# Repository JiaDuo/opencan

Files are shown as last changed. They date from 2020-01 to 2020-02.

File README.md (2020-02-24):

# opencan
linux系统下开源的can测试工具
基于linux驱动中slcan协议实现socketcan的通信  

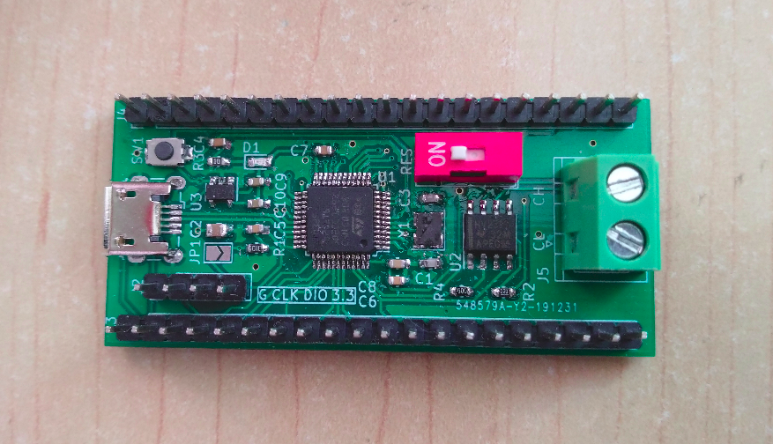
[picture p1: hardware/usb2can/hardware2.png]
Image text


## 硬件介绍  
硬件使用MicroUSB和PC主机通信，支持一路CAN 2.0B，最大波特率1Mbps
## 更新固件
使用stlink/jlink连接到J2引脚，CLK DIO GND  

linux系统下安装stlink-tools  
apt install stlink-tools  

下载固件到MCU中  
st-flash --reset write ./build/usb2can.bin 0x08000000  

## 使用
基于slcan/socketcan的软件都可以应用到当前设备，python-can、can-utils等     
* 安装can-utils  
apt install can-utils
* 建立socketcan设备  
slcand -o -s8 /dev/ttyACM0 can0   
ip link set up can0
* 收发报文
可以使用ifconfig查看can网络状态，使用can-utils中提供的软件来进行报文收发  
eg：  
candump can0  
cansniffer -c can0  
cansend can0 123#R3  

## 一些参考文档
[slcan]https://elinux.org/Bringing_CAN_interface_up  
[slcan-api]https://github.com/linux-can/can-misc/blob/master/docs/SLCAN-API.pdf

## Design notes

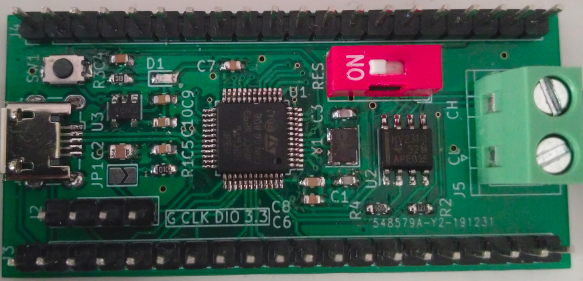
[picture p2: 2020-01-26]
hardware/usb2can/hardware.png

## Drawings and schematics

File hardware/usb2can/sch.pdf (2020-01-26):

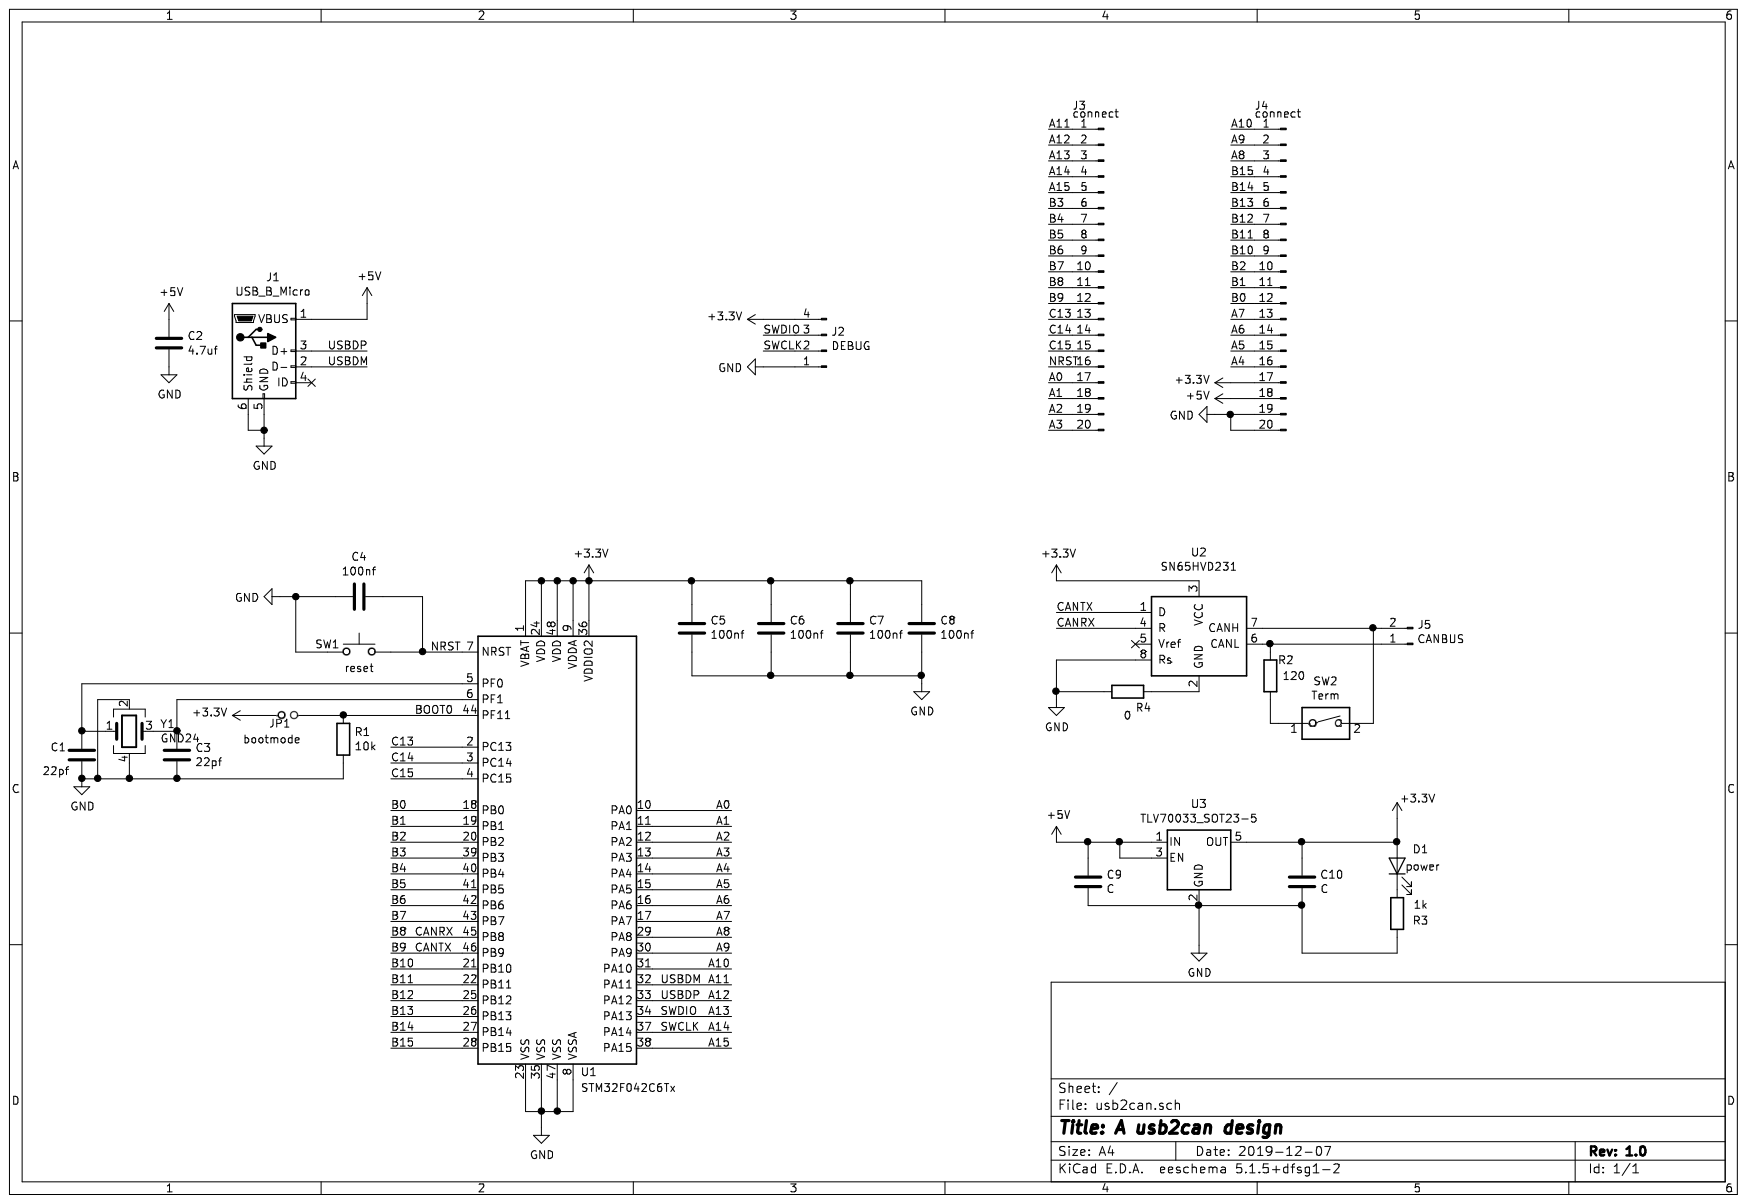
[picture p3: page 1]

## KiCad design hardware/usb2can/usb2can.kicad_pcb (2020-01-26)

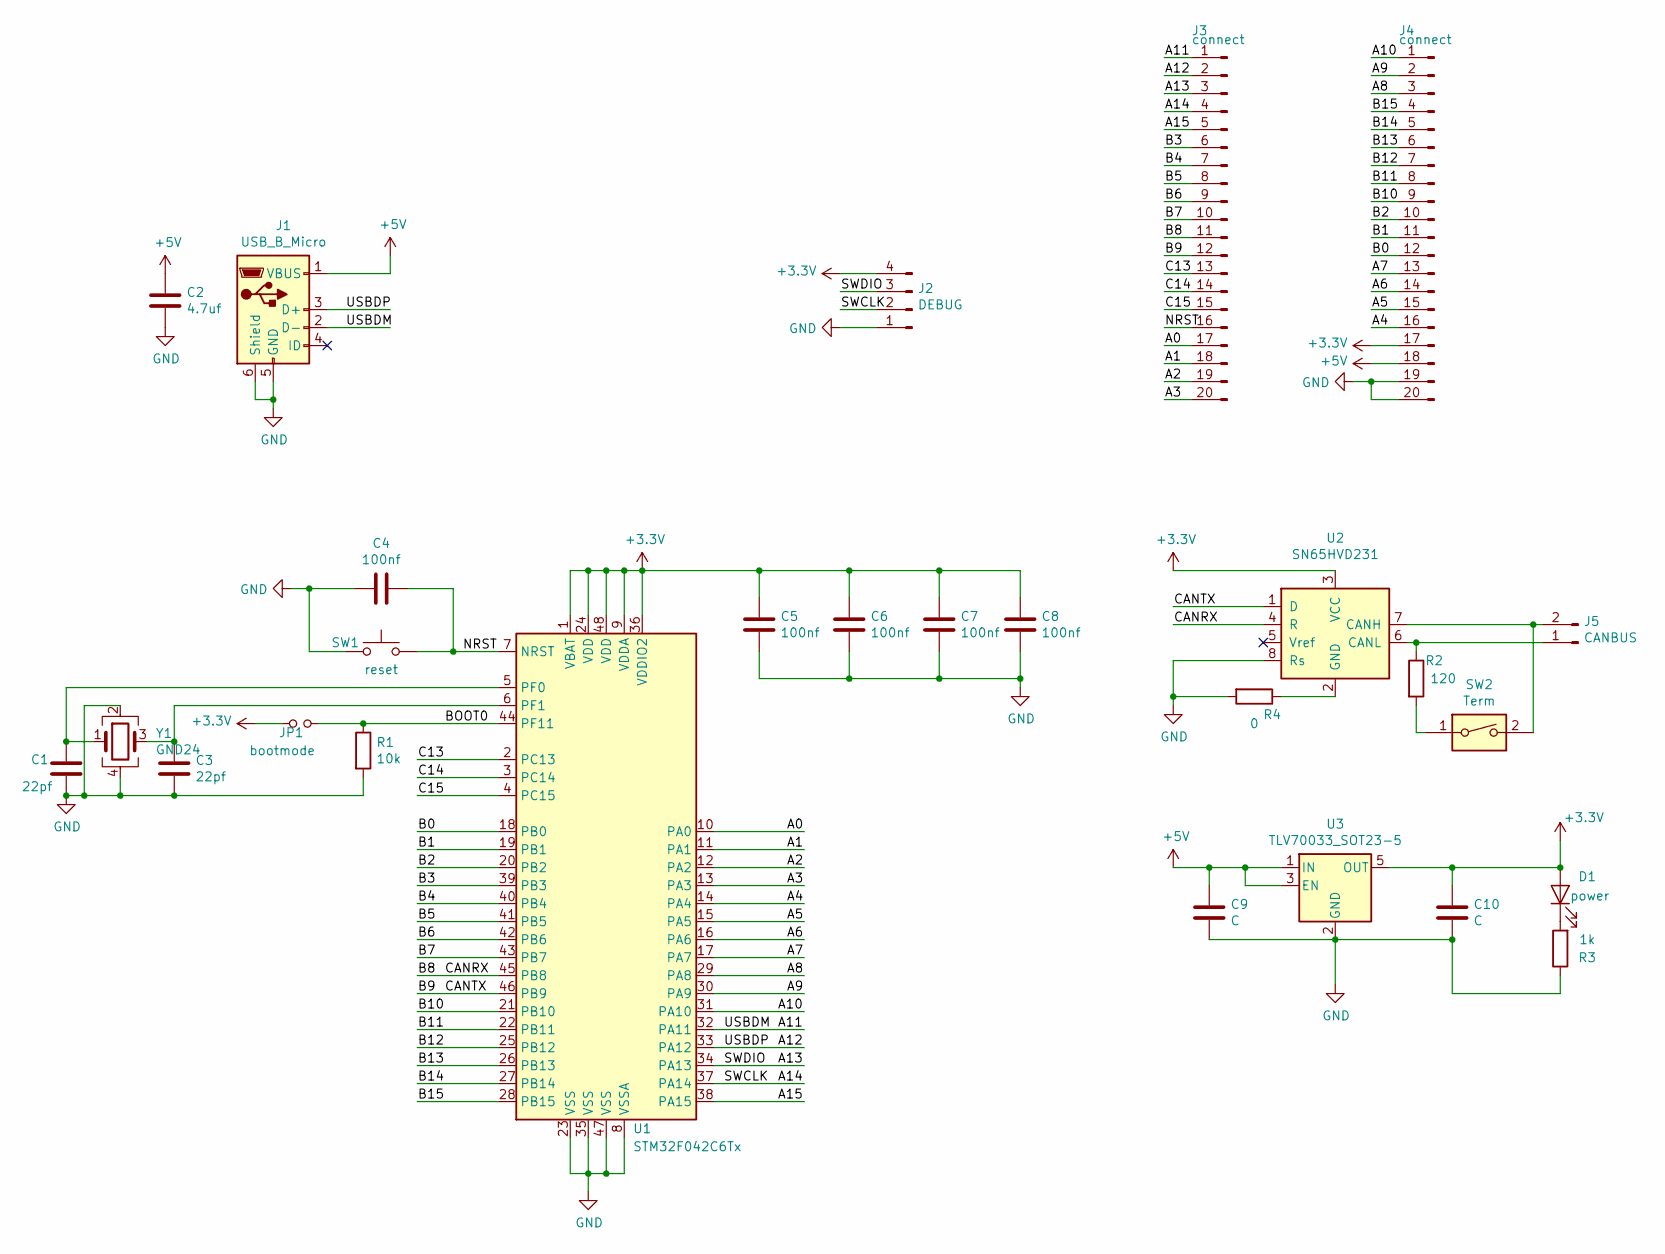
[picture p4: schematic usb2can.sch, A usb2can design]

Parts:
C1, C3: 22pf; C_0603_1608Metric
C2: 4.7uf; C_0805_2012Metric
C4, C5, C6, C7, C8: 100nf; C_0603_1608Metric
C9, C10: C; C_0603_1608Metric
D1: power; LED_0603_1608Metric
J1: USB_B_Micro; USB_Micro-B_Wuerth_629105150521
J2: DEBUG; PinHeader_1x04_P2.54mm_Vertical
J3, J4: connect; PinHeader_1x20_P2.54mm_Vertical
J5: CANBUS; PhoenixContact_MSTBVA_2,5_2-G_1x02_P5.00mm_Vertical
JP1: bootmode; SolderJumper-2_P1.3mm_Open_TrianglePad1.0x1.5mm
R1: 10k; R_0603_1608Metric
R2: 120; R_0603_1608Metric
R3: 1k; R_0603_1608Metric
R4: 0; R_0603_1608Metric
SW1: reset; SW_SPST_B3U-1000P
SW2: Term; SW_DIP_SPSTx01_Slide_9.78x4.72mm_W7.62mm_P2.54mm
U1: STM32F042C6Tx; LQFP-48_7x7mm_P0.5mm
U2: SN65HVD231; SOIC-8_3.9x4.9mm_P1.27mm
U3: TLV70033_SOT23-5; SOT-23-5
Y1: GND24; Crystal_SMD_3225-4Pin_3.2x2.5mm

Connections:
+3V3: C5.2, C6.2, C7.2, C8.2, C10.1, D1.2 (A), J2.4, J4.17, JP1.1, U1.1 (VBAT), U1.9 (VDDA), U1.24 (VDD), U1.36 (VDDIO2), U1.48 (VDD), U2.3 (VCC), U3.5 (OUT)
+5V: C2.1, C9.1, J1.1 (VBUS), J4.18, U3.1 (IN), U3.3 (EN)
/A0: J3.17, U1.10 (PA0)
/A1: J3.18, U1.11 (PA1)
/A2: J3.19, U1.12 (PA2)
/A3: J3.20, U1.13 (PA3)
/A4: J4.16, U1.14 (PA4)
/A5: J4.15, U1.15 (PA5)
/A6: J4.14, U1.16 (PA6)
/A7: J4.13, U1.17 (PA7)
/A8: J4.3, U1.29 (PA8)
/A9: J4.2, U1.30 (PA9)
/A10: J4.1, U1.31 (PA10)
/A11: J1.2 (D-), J3.1, U1.32 (PA11)
/A12: J1.3 (D+), J3.2, U1.33 (PA12)
/A13: J2.3, J3.3, U1.34 (PA13)
/A14: J2.2, J3.4, U1.37 (PA14)
/A15: J3.5, U1.38 (PA15)
/B0: J4.12, U1.18 (PB0)
/B1: J4.11, U1.19 (PB1)
/B2: J4.10, U1.20 (PB2)
/B3: J3.6, U1.39 (PB3)
/B4: J3.7, U1.40 (PB4)
/B5: J3.8, U1.41 (PB5)
/B6: J3.9, U1.42 (PB6)
/B7: J3.10, U1.43 (PB7)
/B8: J3.11, U1.45 (PB8), U2.4 (R)
/B9: J3.12, U1.46 (PB9), U2.1 (D)
/B10: J4.9, U1.21 (PB10)
/B11: J4.8, U1.22 (PB11)
/B12: J4.7, U1.25 (PB12)
/B13: J4.6, U1.26 (PB13)
/B14: J4.5, U1.27 (PB14)
/B15: J4.4, U1.28 (PB15)
/BOOT0: JP1.2, R1.1, U1.44 (PF11)
/C13: J3.13, U1.2 (PC13)
/C14: J3.14, U1.3 (PC14)
/C15: J3.15, U1.4 (PC15)
/NRST: C4.1, J3.16, SW1.2, U1.7 (NRST)
GND: C1.2, C2.2, C3.2, C4.2, C5.1, C6.1, C7.1, C8.1, C9.2, C10.2, J1.5 (GND), J1.6 (Shield), J2.1, J4.19, J4.20, R1.2, R3.1, R4.2, SW1.1, U1.8 (VSSA), U1.23 (VSS), U1.35 (VSS), U1.47 (VSS), U2.8 (Rs), U3.2 (GND), Y1.2, Y1.4
unnamed: C1.1, U1.5 (PF0), Y1.1
unnamed: C3.1, U1.6 (PF1), Y1.3
unnamed: D1.1 (K), R3.2
unnamed: J5.1, R2.1, U2.6 (CANL)
unnamed 45: J5.2, SW2.2, U2.7 (CANH); also elsewhere on the board
unnamed 46: R2.2, SW2.1; also elsewhere on the board
unnamed: R4.1, U2.2 (GND)

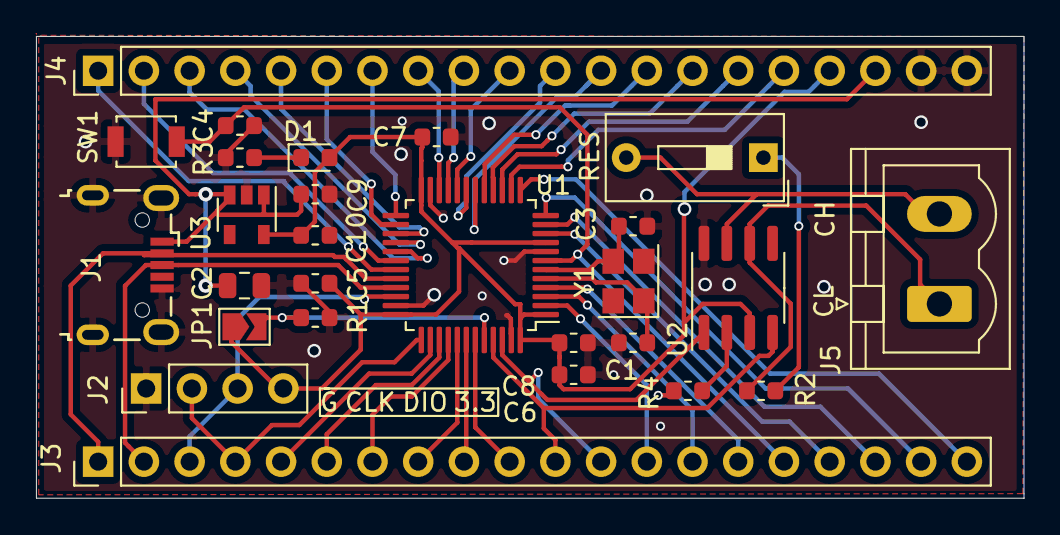
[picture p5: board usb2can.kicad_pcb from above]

Board: 2 copper layers, 54.9 x 25.7 mm, 27 parts (0 on the bottom side), 47 nets.

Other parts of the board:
RES: Term; SW_DIP_SPSTx01_Slide_9.78x4.72mm_W7.62mm_P2.54mm

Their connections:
unnamed 45: RES.2; also elsewhere on the board
unnamed 46: RES.1; also elsewhere on the board

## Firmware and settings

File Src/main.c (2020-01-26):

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

/* Includes ------------------------------------------------------------------*/
#include "main.h"
#include "usb_device.h"

/* USER CODE BEGIN Includes */
#include "usbd_cdc_if.h"
/* USER CODE END Includes */

CAN_HandleTypeDef hcan;

void SystemClock_Config(void);
static void MX_GPIO_Init(void);
static void MX_CAN_Init(void);
/**
  * @brief  The application entry point.
  * @retval int
  */
int main(void)
{
  

  /* MCU Configuration--------------------------------------------------------*/

  /* Reset of all peripherals, Initializes the Flash interface and the Systick. */
  HAL_Init();

  /* Configure the system clock */
  SystemClock_Config();

  /* Initialize all configured peripherals */
  MX_GPIO_Init();
  MX_USB_DEVICE_Init();
  MX_CAN_Init();
  /* Infinite loop */
  /* USER CODE BEGIN WHILE */

  while (1)
  {
    /* USER CODE END WHILE */

    /* USER CODE BEGIN 3 */
  }
  /* USER CODE END 3 */
}

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
/* USER CODE BEGIN 4 */
void function_test()
{
    //usb serial test
    HAL_Delay(500);
    CDC_Transmit_FS((uint8_t*)"t1234DEADBEEF\r",14);
    HAL_Delay(500);
    CDC_Transmit_FS((uint8_t*)"t1234DEADBEE8\r",14);

    //can test
    CAN_TxHeaderTypeDef can_tx_header;
    CAN_RxHeaderTypeDef can_rx_header;
    can_tx_header.DLC=8;
    can_tx_header.IDE = CAN_ID_STD;
    can_tx_header.RTR = CAN_RTR_DATA;
    can_tx_header.StdId = 0x33;
    uint32_t txmail;
    uint8_t can_tx_buf[8]={1,2,3,4,5,6,7,8};
    uint8_t can_rx_buf[8]={0};
    
    HAL_CAN_AddTxMessage(&hcan,&can_tx_header,can_tx_buf,&txmail); //send test

    if (HAL_CAN_GetRxMessage(&hcan,CAN_RX_FIFO0,&can_rx_header,can_rx_buf) == HAL_OK)
    { //recv test
      can_tx_header.DLC = can_rx_header.DLC;
      can_tx_header.ExtId = can_rx_header.ExtId;
      can_tx_header.IDE  = can_rx_header.IDE;
      can_tx_header.RTR = can_rx_header.RTR;
      can_tx_header.StdId = can_rx_header.StdId;
      HAL_CAN_AddTxMessage(&hcan,&can_tx_header,can_rx_buf,&txmail);
    }  
}

/* USER CODE END 4 */
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


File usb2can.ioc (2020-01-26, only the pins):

Mcu.UserName=STM32F042C6Tx
PA11.Signal=USB_DM
PA12.Signal=USB_DP
PA13.Signal=SYS_SWDIO
PA14.Signal=SYS_SWCLK
PB8.Signal=CAN_RX
PB9.Signal=CAN_TX
PF0-OSC_IN.Signal=RCC_OSC_IN
PF1-OSC_OUT.Signal=RCC_OSC_OUT

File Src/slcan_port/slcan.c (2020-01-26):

#include "slcan.h"



char cmd_buf[CMD_BUF_MAX]={0};
int	cmd_buf_off = 0;

/* hcan.Init.Prescaler value 8=1Mbps*/
const uint32_t bitrate_map[9]={800,400,160,80,64,32,16,10,8};
const char hex_str_map[16]={'0','1','2','3','4','5','6','7','8','9','A','B','C','D','E','F'};

/* slcan response function */
#define cmd_response(buf,len) {\
	CDC_Transmit_FS((uint8_t*)buf,len);\
}

/* rx stand frame to cmd str */
void sff_to_cmd(CAN_RxHeaderTypeDef* header,uint8_t data[])
{
	StandFrame_def cmd_frame;
	uint32_t cmd_len;
	cmd_frame.cmd = CMD_SFF;
	int2hex(header->StdId,3,cmd_frame.id);
	int2hex(header->DLC,1,&cmd_frame.len);
	for(cmd_len = 0;cmd_len < header->DLC;cmd_len++)
	{
		int2hex(data[cmd_len],2,cmd_frame.data+(cmd_len<<1));
	}
	cmd_len = ((header->DLC)<<1) + 5 + 1;
	((uint8_t*)&cmd_frame)[cmd_len-1] = CMD_CR;
	cmd_response(&cmd_frame,cmd_len);
}

/* rx extend frame to cmd str */
void eff_to_cmd(CAN_RxHeaderTypeDef* header,uint8_t data[])
{
	ExtendFrame_def cmd_frame;
	uint32_t cmd_len;
	cmd_frame.cmd = CMD_EFF;
	int2hex(header->ExtId,8,cmd_frame.id);
	int2hex(header->DLC,1,&cmd_frame.len);
	for(cmd_len = 0;cmd_len < header->DLC;cmd_len++)
	{
		int2hex(data[cmd_len],2,cmd_frame.data+(cmd_len<<1));
	}
	cmd_len = ((header->DLC)<<1) + 10 + 1;
	((uint8_t*)&cmd_frame)[cmd_len-1] = CMD_CR;
	cmd_response(&cmd_frame,cmd_len);
}

/* rx remote request stand frame to cmd str */
void rsff_to_cmd(CAN_RxHeaderTypeDef* header)
{
	RemoteStandFrame_def cmd_frame;
	uint32_t cmd_len;
	cmd_frame.cmd = CMD_RSFF;
	int2hex(header->StdId,3,cmd_frame.id);
	int2hex(header->DLC,1,&cmd_frame.len);
	cmd_len = 6;
	cmd_frame.cr = CMD_CR;
	cmd_response(&cmd_frame,cmd_len);
}

/* rx remote request extend frame to cmd str */
void reff_to_cmd(CAN_RxHeaderTypeDef* header)
{
	RemoteExtendFrame_def cmd_frame;
	uint32_t cmd_len;
	cmd_frame.cmd = CMD_REFF;
	int2hex(header->ExtId,8,cmd_frame.id);
	int2hex(header->DLC,1,&cmd_frame.len);
	cmd_len = 11;
	cmd_frame.cr = CMD_CR;
	cmd_response(&cmd_frame,cmd_len);
}

/* can recv interrupt callback */
void HAL_CAN_RxFifo0MsgPendingCallback(CAN_HandleTypeDef *hcan)
{
	CAN_RxHeaderTypeDef can_rx_header;
	uint8_t can_rx_buf[8];
	int8_t can_rx_count = HAL_CAN_GetRxFifoFillLevel(hcan,CAN_RX_FIFO0);
	for(;can_rx_count > 0;can_rx_count--)
	{
		if (HAL_CAN_GetRxMessage(hcan,CAN_RX_FIFO0,&can_rx_header,can_rx_buf) == HAL_OK)
		{ 
			if(can_rx_header.IDE == CAN_ID_STD)
			{
				if(can_rx_header.RTR == CAN_RTR_DATA)
				{
					sff_to_cmd(&can_rx_header,can_rx_buf);
				}
				else if(can_rx_header.RTR == CAN_RTR_REMOTE)
				{
					rsff_to_cmd(&can_rx_header);
				}
			}
			else if(can_rx_header.IDE == CAN_ID_EXT)
			{
				if(can_rx_header.RTR == CAN_RTR_DATA)
				{
					eff_to_cmd(&can_rx_header,can_rx_buf);
				}
				else if(can_rx_header.RTR == CAN_RTR_REMOTE)
				{
					reff_to_cmd(&can_rx_header);
				}
			}
		} 
	}
}

/* set can bitrate */
/* only change the hcan.Init.Prescaler value = 6 = 1Mbps*/
/* This command is only active if the CAN channel is closed */
void cmd_set_bitrate(char *cmd){
	uint8_t res_code=CMD_CR;
	SetupBitrate_def *p = (SetupBitrate_def*)cmd;
	if (hcan.State == HAL_CAN_STATE_READY){
		hcan.Init.Prescaler = bitrate_map[hex2int(&(p->speed),1)];
		if (HAL_CAN_Init(&hcan) != HAL_OK)
		{
			res_code = CMD_BELL;
		}
	}else{
		res_code = CMD_BELL;
	}
	cmd_response(&res_code,1);
}

/* return the version */
void cmd_version(char *cmd){
	char res_code[6]={CMD_VER,};
	res_code[1] = HW_VERSION[0];
	res_code[2] = HW_VERSION[1];
	res_code[3] = SW_VERSION[0];
	res_code[4] = SW_VERSION[1];
	res_code[5] = CMD_CR;
	cmd_response(res_code,6);
}

/* return the serial number */
void cmd_sn(char *cmd){
	char res_code[6]={CMD_SN,};
	/* Read MCU Id, 32-bit access */
	uint32_t MCU_Id = DBGMCU->IDCODE;
	int2hex(MCU_Id,4,res_code + 1);
	res_code[5] = CMD_CR;
	cmd_response(res_code,6);
}

/* set btr , not used!! */
void cmd_set_btr(char *cmd){
	uint8_t btr0=0,btr1=0;
	btr0 = hex2int(((SetupBtr_def*)cmd)->btr0,2);
	btr1 = hex2int(((SetupBtr_def*)cmd)->btr1,2);
	cmd_response(CMD_ACK,1);
	UNUSED(btr0);
	UNUSED(btr1);
}

/* open can */
void cmd_open(){
	uint8_t res_code=CMD_CR;
	if (HAL_CAN_Start(&hcan) != HAL_OK){
		res_code = CMD_BELL;
	}
	cmd_response(&res_code,1);
}

/* close can */
void cmd_close(){
	uint8_t res_code=CMD_CR;
	if (HAL_CAN_Stop(&hcan) != HAL_OK){
		res_code = CMD_BELL;
	}
	cmd_response(&res_code,1);
}

/* timestamp set, not used!! */
void cmd_timestamp(char *cmd){
	uint8_t onoff = hex2int(&((TimeStamp_def *)cmd)->timestamp,1);
	cmd_response(CMD_ACK,1);
	UNUSED(onoff);
}

/* tx stand can frame*/
void cmd_sff(char *cmd){
	uint8_t can_data[8]={0};
	uint8_t i;
	uint32_t mailbox;
	uint8_t res_code[2];
	CAN_TxHeaderTypeDef can_tx_header;
	StandFrame_def *p = (StandFrame_def*)cmd;
	can_tx_header.StdId = hex2int(p->id,3);
	can_tx_header.DLC = hex2int(&p->len,1);
	can_tx_header.IDE = CAN_ID_STD;
	can_tx_header.RTR = CAN_RTR_DATA;
	for(i=0;i<can_tx_header.DLC;i++){
		can_data[i] = hex2int(p->data+(i<<1),2);
	}
	if(HAL_CAN_AddTxMessage(&hcan,&can_tx_header,can_data,&mailbox) == HAL_OK){
		cmd_response("z\r",2);
	}
	else{
		res_code[0]=CMD_BELL;
		cmd_response(res_code,1);
	}
}

/* tx extend can frame*/
void cmd_eff(char *cmd){
	uint8_t can_data[8]={0};
	uint8_t i;
	uint32_t mailbox;
	uint8_t res_code[2];
	CAN_TxHeaderTypeDef can_tx_header;
	ExtendFrame_def *p = (ExtendFrame_def*)cmd;
	can_tx_header.ExtId = hex2int(p->id,8);
	can_tx_header.DLC = hex2int(&p->len,1);
	can_tx_header.IDE = CAN_ID_EXT;
	can_tx_header.RTR = CAN_RTR_DATA;
	for(i=0;i<can_tx_header.DLC;i++){
		can_data[i] = hex2int(p->data+(i<<1),2);
	}
	if(HAL_CAN_AddTxMessage(&hcan,&can_tx_header,can_data,&mailbox) == HAL_OK){
		cmd_response("z\r",2);
	}
	else{
		res_code[0]=CMD_BELL;
		cmd_response(res_code,1);
	}
}

/* tx remote request stand can frame*/
void cmd_rsff(char *cmd){
	uint8_t can_data[8]={0};
	uint32_t mailbox;
	uint8_t res_code[2];
	CAN_TxHeaderTypeDef can_tx_header;
	RemoteStandFrame_def *p = (RemoteStandFrame_def*)cmd;
	can_tx_header.StdId = hex2int(p->id,3);
	can_tx_header.DLC = hex2int(&p->len,1);
	can_tx_header.IDE = CAN_ID_STD;
	can_tx_header.RTR = CAN_RTR_REMOTE;
	if(HAL_CAN_AddTxMessage(&hcan,&can_tx_header,can_data,&mailbox) == HAL_OK){
		cmd_response("z\r",2);
	}
	else{
		res_code[0]=CMD_BELL;
		cmd_response(res_code,1);
	}
}

/* tx remote request extend can frame*/
void cmd_reff(char *cmd){
	uint8_t can_data[8]={0};
	uint32_t mailbox;
	uint8_t res_code[2];
	CAN_TxHeaderTypeDef can_tx_header;
	RemoteExtendFrame_def *p = (RemoteExtendFrame_def*)cmd;
	can_tx_header.ExtId = hex2int(p->id,8);
	can_tx_header.DLC = hex2int(&p->len,1);
	can_tx_header.IDE = CAN_ID_EXT;
	can_tx_header.RTR = CAN_RTR_REMOTE;
	if(HAL_CAN_AddTxMessage(&hcan,&can_tx_header,can_data,&mailbox) == HAL_OK){
		cmd_response("z\r",2);
	}
	else{
		res_code[0]=CMD_BELL;
		cmd_response(res_code,1);
	}
}
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

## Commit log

2020-01-26 添加工程
    [usb2can-B_Cu.gbr, usb2can-B_Mask.gbr, usb2can-B_Paste.gbr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]
2020-01-26 增加预览图片

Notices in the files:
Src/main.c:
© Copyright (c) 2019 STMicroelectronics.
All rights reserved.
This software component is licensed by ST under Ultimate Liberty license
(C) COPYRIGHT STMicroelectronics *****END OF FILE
